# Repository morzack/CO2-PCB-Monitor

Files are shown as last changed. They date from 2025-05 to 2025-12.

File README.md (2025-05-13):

# CO2-PCB-Monitor

This repo contains the hardware and software required to manufacture and assemble a small seven segment CO2 monitor.

The monitor is built around a 4 digit seven segment display (with automatic dimming based on ambient light) that displays the current atmospheric CO2 concentration as measured by an Adafruit SCD-40 module over i2c.



In practice, this project can serve as a generic platform for any i2c module that might benefit from a 4 digit display. Potentially, other projects could be built around this architecture.

There is a BOM included: the total cost per unit, as of when it was made in early 2025, was ~90 USD.
Most of the cost comes from the SCD-40 module used -- directly integrating one of the modules onto the board should lower that price.

A rough block diagram is below:



The system has two power domains: a 5V domain is used for all digital logic, while the 3V domain is reserved for the seven-segement characters and associated dimming circuit.
This separation of power supplies was chosen to both allow for a soft startup sequence (putting less strain on the overall power supply), and to remove some voltage headroom for the LEDs.

The final design was manufactured using JLCPCB's services. A BOM is included with this repo, as well as manufacturing files.

The board can be programmed using the Arduino IDE and a separate ISP over the SPI lines.

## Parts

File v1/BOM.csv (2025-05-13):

Reference | Value | Datasheet | Footprint | Qty | DNP | stock_idx | Digikey | price per
J2 | Conn_02x03_Odd_Even | ~ | Connector_PinHeader_2.54mm:PinHeader_2x03_P2.54mm_Vertical | 1 |  | 1
JP1 | 3v3_or | ~ | Jumper:SolderJumper-2_P1.3mm_Open_Pad1.0x1.5mm | 1 |  | 1
C9 | 10u | ~ | Capacitor_SMD:C_0805_2012Metric_Pad1.18x1.45mm_HandSolder | 1 |  | 1 | https://www.digikey.com/en/products/detail/samsung-electro-mechanics/CL21A106KOQNNNE/3886754 | 0.08 | 0.08
C3,C10 | 0.1u | ~ | Capacitor_SMD:C_0805_2012Metric_Pad1.18x1.45mm_HandSolder | 2 |  | 2 | https://www.digikey.com/en/products/detail/yageo/CC0805KRX7R9BB104/302874 | 0.08 | 0.16
C4,C5,C6,C7,C8 | 100n | ~ | Capacitor_SMD:C_0805_2012Metric_Pad1.18x1.45mm_HandSolder | 5 |  | 11 | https://www.digikey.com/en/products/detail/samsung-electro-mechanics/CL21B104KBCNFNC/3888102 | 0.1 | 0.5
U1 | ATmega328P-A | http://ww1.microchip.com/downloads/en/DeviceDoc/ATmega328_P%20AVR%20MCU%20with%20picoPower%20Technology%20Data%20Sheet%2040001984A.pdf | Package_QFP:TQFP-32_7x7mm_P0.8mm | 1 |  | 25 | https://www.digikey.com/en/products/detail/microchip-technology/ATMEGA328P-AUR/2357086 | 2.74 | 2.74
Y1 | 16MHz | ~ | inv_footprints:XTAL_ECS-160-18-23A-EN-TR | 1 |  | 28 | https://www.digikey.com/en/products/detail/ecs-inc/ECS-160-18-23A-EN-TR/2213741 | 0.86 | 0.86
U2 | ~ |  | inv_footprints:scd_40 | 1 |  | 34 | https://www.digikey.com/en/products/detail/adafruit-industries-llc/5187/15194668 | 44.95 | 44.95
Q3 | 2N3904 | https://www.onsemi.com/pub/Collateral/2N3903-D.PDF | Package_TO_SOT_THT:TO-92_Inline | 1 |  | 36 | https://www.digikey.com/en/products/detail/onsemi/2N3904BU/1413 | 0.28 | 0.28
R7 | R_Photo | ~ | OptoDevice:R_LDR_5.1x4.3mm_P3.4mm_Vertical | 1 |  | 38 | https://www.digikey.com/en/products/detail/advanced-photonix/PDV-P9008/480625 | 1.49 | 1.49
U3 | MAX7221xNG | https://datasheets.maximintegrated.com/en/ds/MAX7219-MAX7221.pdf | Package_DIP:DIP-24_W7.62mm_Socket | 1 |  | 39 | https://www.digikey.com/en/products/detail/analog-devices-inc-maxim-integrated/MAX7219ENG/774127 | 18.67 | 18.67
Q1,Q2 | 2N3906 | https://www.onsemi.com/pub/Collateral/2N3906-D.PDF | Package_TO_SOT_THT:TO-92_Inline | 2 |  | 40 | https://www.digikey.com/en/products/detail/onsemi/2N3906BU/1414 | 0.27 | 0.54
SW1 | SW_Push | ~ | inv_footprints:SKQGADE010 | 1 |  | 44 | https://www.digikey.com/en/products/detail/c-k/RS-187R05A2-DS-MT-RT/2747186 | 0.72 | 0.72
LED1,LED2,LED3,LED4 | LDS-C814RI | LDS-C814RI | inv_footprints:LDS-C814RI_LUM | 4 |  | 50 | https://www.digikey.com/en/products/detail/lumex-opto-components-inc/LDS-C814RI/252593 | 2.25 | 9
R1,R6 | 10k | ~ | Resistor_SMD:R_0805_2012Metric_Pad1.20x1.40mm_HandSolder | 2 |  | 51 | https://www.digikey.com/en/products/detail/yageo/RC0805FR-0710KL/727535 | 0.14 | 0.28
R4,R8,R10,R11,R12 | 100k | ~ | Resistor_SMD:R_0805_2012Metric_Pad1.20x1.40mm_HandSolder | 5 |  | 54 | https://www.digikey.com/en/products/detail/yageo/RC0805FR-07100KL/727544 | 0.1 | 0.5
R5 | 1k | ~ | Resistor_SMD:R_0805_2012Metric_Pad1.20x1.40mm_HandSolder | 1 |  | 56 | https://www.digikey.com/en/products/detail/yageo/RC0805FR-071KL/727444 | 0.1 | 0.1
R2,R3 | 5.1k | ~ | Resistor_SMD:R_0805_2012Metric_Pad1.20x1.40mm_HandSolder | 2 |  | 60 | https://www.digikey.com/en/products/detail/panasonic-electronic-components/ERJ-6GEYJ512V/46122 | 0.1 | 0.2
C1,C2 | 18p | ~ | Capacitor_SMD:C_0805_2012Metric_Pad1.18x1.45mm_HandSolder | 2 |  | 64 | https://www.digikey.com/en/products/detail/kemet/C0805C180M3HACTU/7949065 | 0.1 | 0.2
R9 | 22k | ~ | Resistor_SMD:R_0805_2012Metric_Pad1.20x1.40mm_HandSolder | 1 |  | 65 | https://www.digikey.com/en/products/detail/stackpole-electronics-inc/RMCF0805FT22K1/1760211 | 0.1 | 0.1
U4 | MIC5205-5.0YM5 | http://ww1.microchip.com/downloads/en/DeviceDoc/20005785A.pdf | Package_TO_SOT_SMD:SOT-23-5 | 1 |  | 66 | https://www.digikey.com/en/products/detail/microchip-technology/MIC5205-5-0YM5-TR/771730 | 0.54 | 0.54
U5 | MIC5366-3.3YC5 | http://ww1.microchip.com/downloads/en/DeviceDoc/mic5365.pdf | Package_TO_SOT_SMD:SOT-353_SC-70-5 | 1 |  | 67 | https://www.digikey.com/en/products/detail/microchip-technology/MIC5366-3-3YC5-TR/1868116 | 0.12 | 0.12
C11,C12,C13,C14,C15 | 1u | ~ | Capacitor_SMD:C_0805_2012Metric_Pad1.18x1.45mm_HandSolder | 5 |  | -- mixed values -- | -- mixed values -- | #N/A | #N/A
J1,J3 | Conn_01x02 | ~ | -- mixed values -- | 2 |  | -- mixed values -- | -- mixed values -- | #N/A | #N/A
TOTAL |  |  |  |  |  |  |  |  | 82.03

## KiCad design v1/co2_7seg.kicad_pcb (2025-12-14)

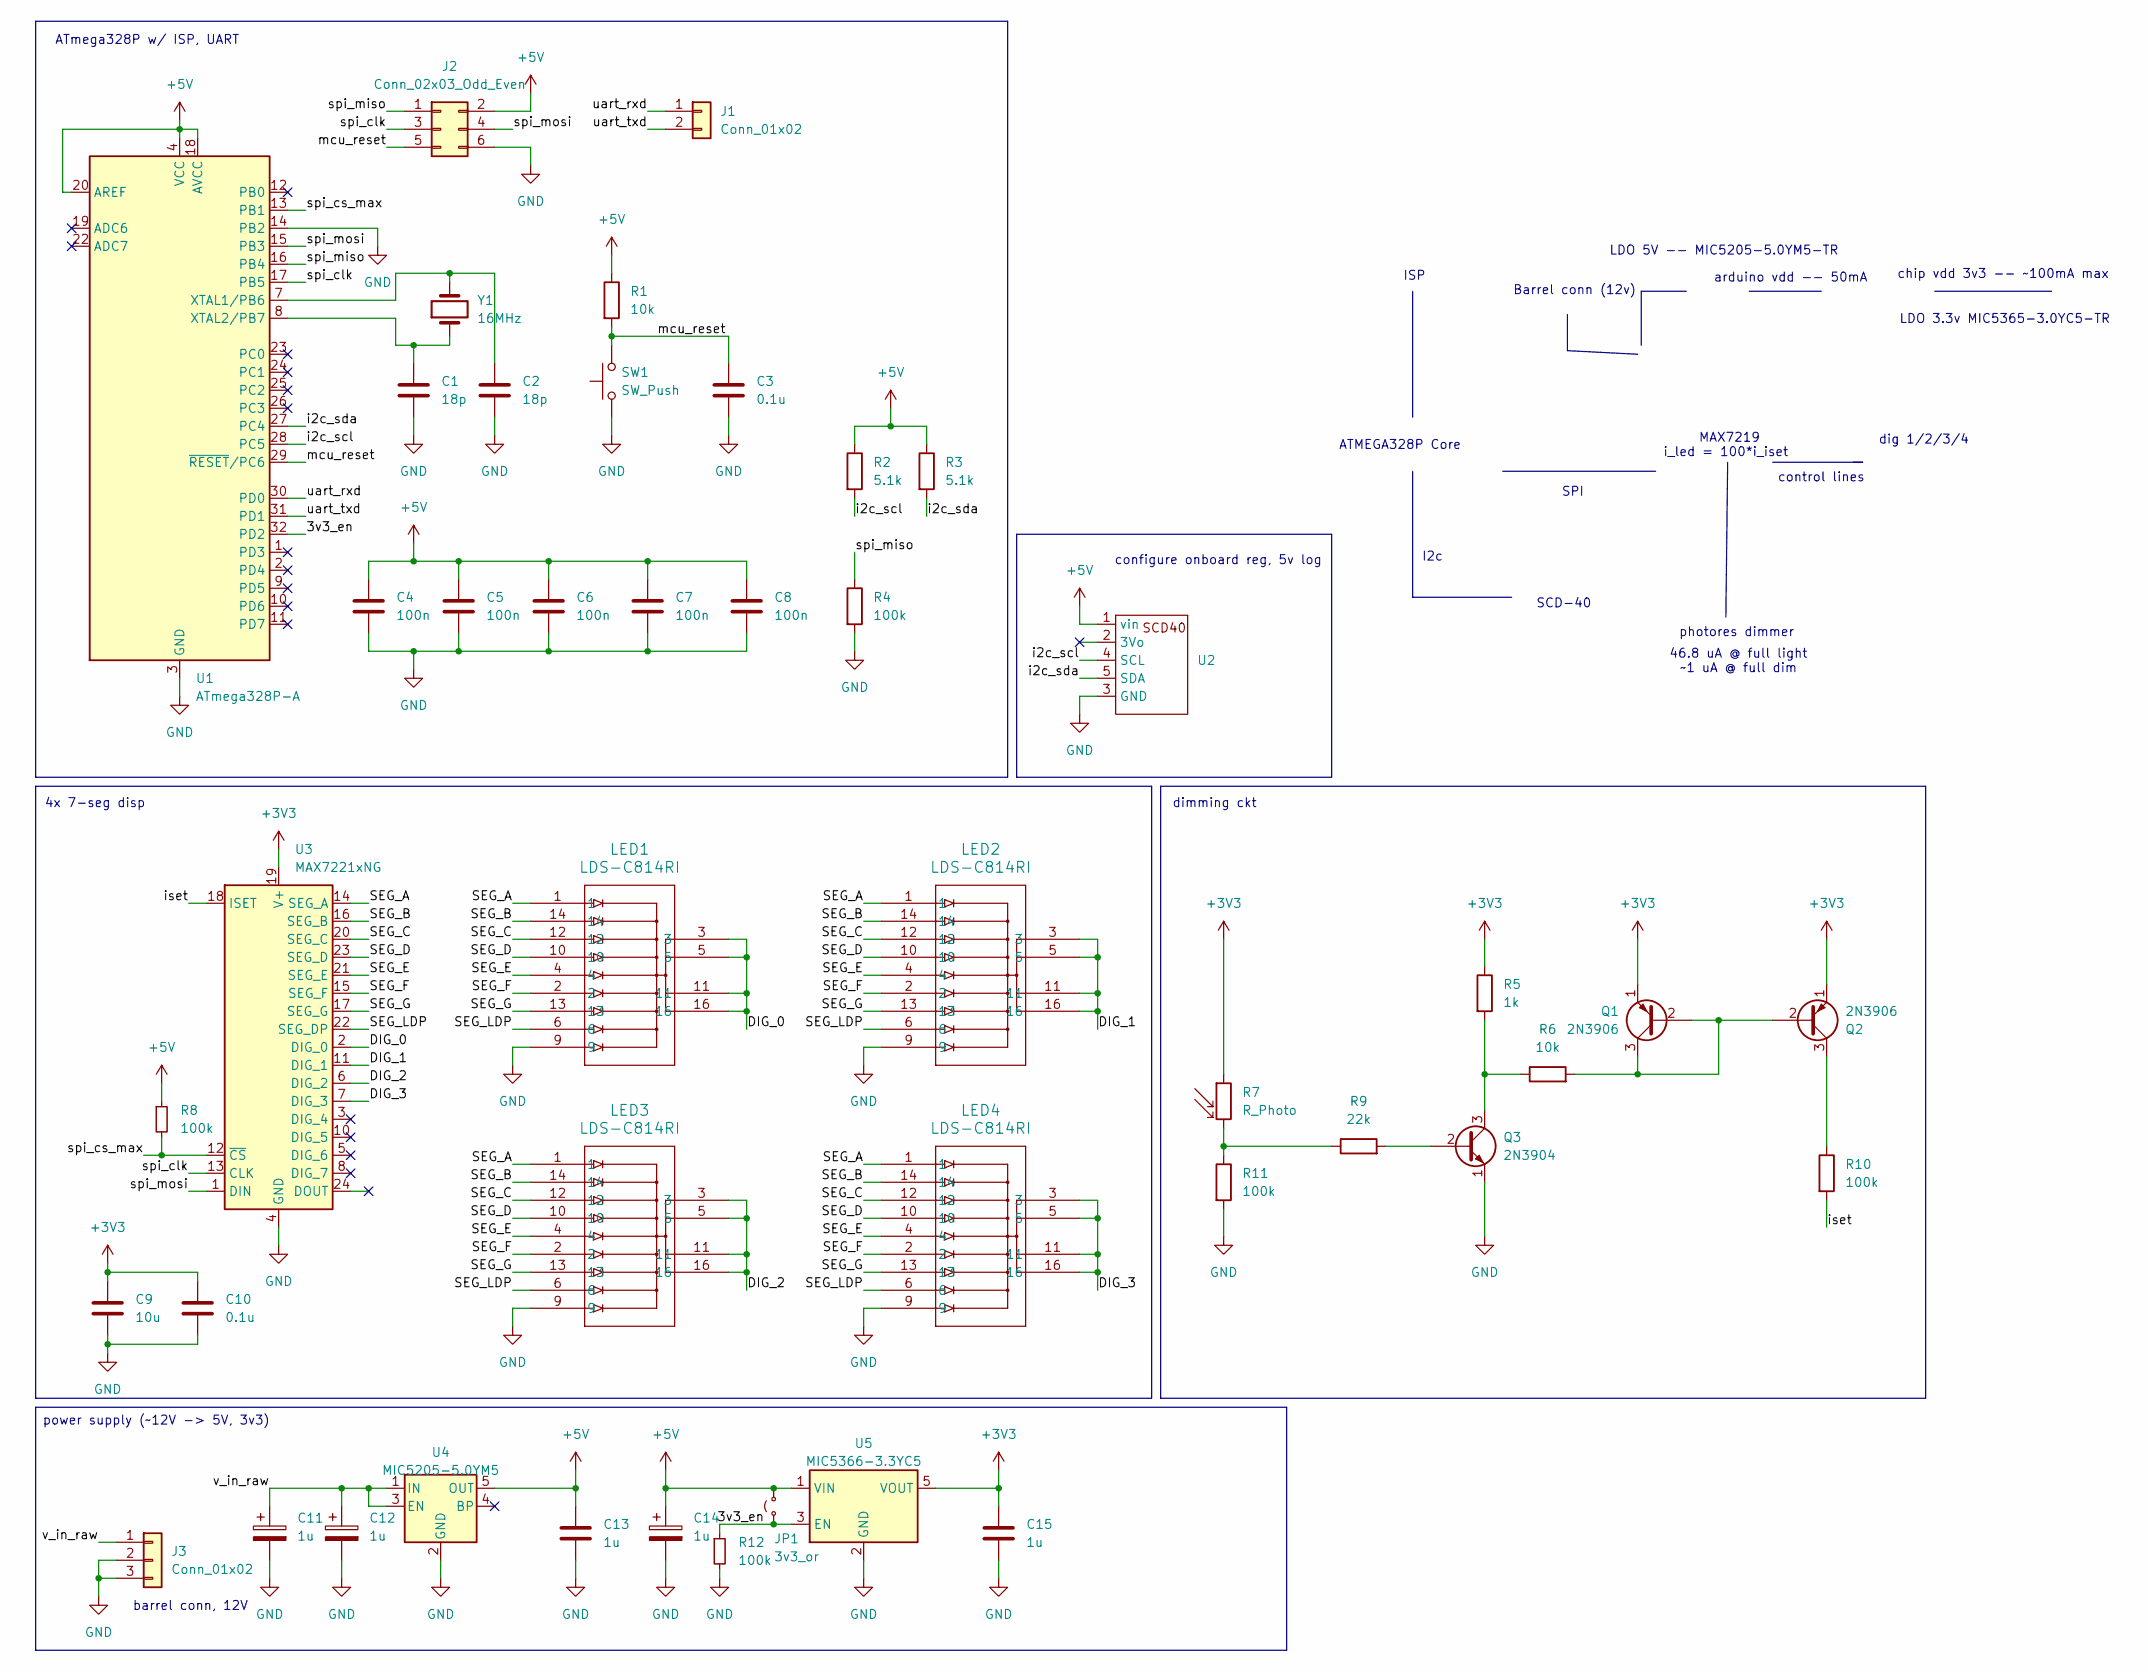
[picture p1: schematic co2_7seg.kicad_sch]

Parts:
C1, C2: 18p; C_0805_2012Metric_Pad1.18x1.45mm_HandSolder
C3, C10: 0.1u; C_0805_2012Metric_Pad1.18x1.45mm_HandSolder
C4, C5, C6, C7, C8: 100n; C_0805_2012Metric_Pad1.18x1.45mm_HandSolder
C9: 10u; C_0805_2012Metric_Pad1.18x1.45mm_HandSolder
C11, C12, C13, C14, C15: 1u; C_0805_2012Metric_Pad1.18x1.45mm_HandSolder
J1: Conn_01x02; PinHeader_1x02_P2.54mm_Vertical
J2: Conn_02x03_Odd_Even; PinHeader_2x03_P2.54mm_Vertical
J3: Conn_01x02; MPD_EJ508A
JP1: 3v3_or; SolderJumper-2_P1.3mm_Open_Pad1.0x1.5mm
LED1, LED2, LED3, LED4: LDS-C814RI; LDS-C814RI_LUM
Q1, Q2: 2N3906; TO-92_Inline
Q3: 2N3904; TO-92_Inline
R1, R6: 10k; R_0805_2012Metric_Pad1.20x1.40mm_HandSolder
R2, R3: 5.1k; R_0805_2012Metric_Pad1.20x1.40mm_HandSolder
R4, R8, R10, R11, R12: 100k; R_0805_2012Metric_Pad1.20x1.40mm_HandSolder
R5: 1k; R_0805_2012Metric_Pad1.20x1.40mm_HandSolder
R7: R_Photo; R_LDR_5.1x4.3mm_P3.4mm_Vertical
R9: 22k; R_0805_2012Metric_Pad1.20x1.40mm_HandSolder
SW1: SW_Push; SKQGADE010
U1: ATmega328P-A; TQFP-32_7x7mm_P0.8mm
U2: scd_40
U3: MAX7221xNG; DIP-24_W7.62mm_Socket
U4: MIC5205-5.0YM5; SOT-23-5
U5: MIC5366-3.3YC5; SOT-353_SC-70-5
Y1: 16MHz; XTAL_ECS-160-18-23A-EN-TR

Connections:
+3V3: C9.1, C10.1, C15.1, Q1.1 (E), Q2.1 (E), R5.1, R7.1, U3.19 (V+), U5.5 (VOUT)
+5V: C4.1, C5.1, C6.1, C7.1, C8.1, C13.1, C14.1, J2.2, JP1.2 (B), R1.1, R2.1, R3.1, R8.1, U1.4 (VCC), U1.6 (VCC), U1.18 (AVCC), U1.20 (AREF), U2.1 (vin), U4.5 (OUT), U5.1 (VIN)
/3v3_en: JP1.1 (A), R12.1, U1.32 (PD2), U5.3 (EN)
/DIG_0: LED1.3, LED1.5, LED1.11, LED1.16, U3.2 (DIG_0)
/DIG_1: LED2.3, LED2.5, LED2.11, LED2.16, U3.11 (DIG_1)
/DIG_2: LED3.3, LED3.5, LED3.11, LED3.16, U3.6 (DIG_2)
/DIG_3: LED4.3, LED4.5, LED4.11, LED4.16, U3.7 (DIG_3)
/SEG_A: LED1.1, LED2.1, LED3.1, LED4.1, U3.14 (SEG_A)
/SEG_B: LED1.14, LED2.14, LED3.14, LED4.14, U3.16 (SEG_B)
/SEG_C: LED1.12, LED2.12, LED3.12, LED4.12, U3.20 (SEG_C)
/SEG_D: LED1.10, LED2.10, LED3.10, LED4.10, U3.23 (SEG_D)
/SEG_E: LED1.4, LED2.4, LED3.4, LED4.4, U3.21 (SEG_E)
/SEG_F: LED1.2, LED2.2, LED3.2, LED4.2, U3.15 (SEG_F)
/SEG_G: LED1.13, LED2.13, LED3.13, LED4.13, U3.17 (SEG_G)
/SEG_LDP: LED1.6, LED2.6, LED3.6, LED4.6, U3.22 (SEG_DP)
/i2c_scl: R2.2, U1.28 (PC5), U2.4 (SCL)
/i2c_sda: R3.2, U1.27 (PC4), U2.5 (SDA)
/iset: R10.2, U3.18 (ISET)
/mcu_reset: C3.1, J2.5, R1.2, SW1.2, U1.29 (~RESET/PC6)
/spi_clk: J2.3, U1.17 (PB5), U3.13 (CLK)
/spi_cs_max: R8.2, U1.13 (PB1), U3.12 (~CS)
/spi_miso: J2.1, R4.1, U1.16 (PB4)
/spi_mosi: J2.4, U1.15 (PB3), U3.1 (DIN)
/uart_rxd: J1.1, U1.30 (PD0)
/uart_txd: J1.2, U1.31 (PD1)
/v_in_raw: C11.1, C12.1, J3.1, U4.1 (IN), U4.3 (EN)
GND: C1.2, C2.2, C3.2, C4.2, C5.2, C6.2, C7.2, C8.2, C9.2, C10.2, C11.2, C12.2, C13.2, C14.2, C15.2, J2.6, J3.2, J3.3, LED1.9, LED2.9, LED3.9, LED4.9, Q3.1 (E), R4.2, R11.2, R12.2, SW1.1, U1.3 (GND), U1.5 (GND), U1.14 (PB2), U1.21 (GND), U2.3 (GND), U3.4 (GND), U3.9 (GND), U4.2 (GND), U5.2 (GND)
unnamed: Q1.2 (B), Q1.3 (C), Q2.2 (B), R6.2
unnamed: Q2.3 (C), R10.1
unnamed: Q3.2 (B), R9.2
unnamed: Q3.3 (C), R5.2, R6.1
unnamed: R7.2, R9.1, R11.1
unnamed: C2.1, U1.7 (XTAL1/PB6), Y1.2
unnamed: C1.1, U1.8 (XTAL2/PB7), Y1.1

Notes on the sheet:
power supply (~12V -> 5V, 3v3)
i_led = 100*i_iset
I2c
control lines
4x 7-seg disp
dig 1/2/3/4
dimming ckt
barrel conn, 12V
LDO 3.3v MIC5365-3.0YC5-TR
46.8 uA @ full light ~1 uA @ full dim
ATMEGA328P Core
photores dimmer
Barrel conn (12v)
LDO 5V -- MIC5205-5.0YM5-TR
configure onboard reg, 5v log
SCD-40
chip vdd 3v3 -- ~100mA max
ATmega328P w/ ISP, UART
MAX7219
ISP
SPI
arduino vdd -- 50mA

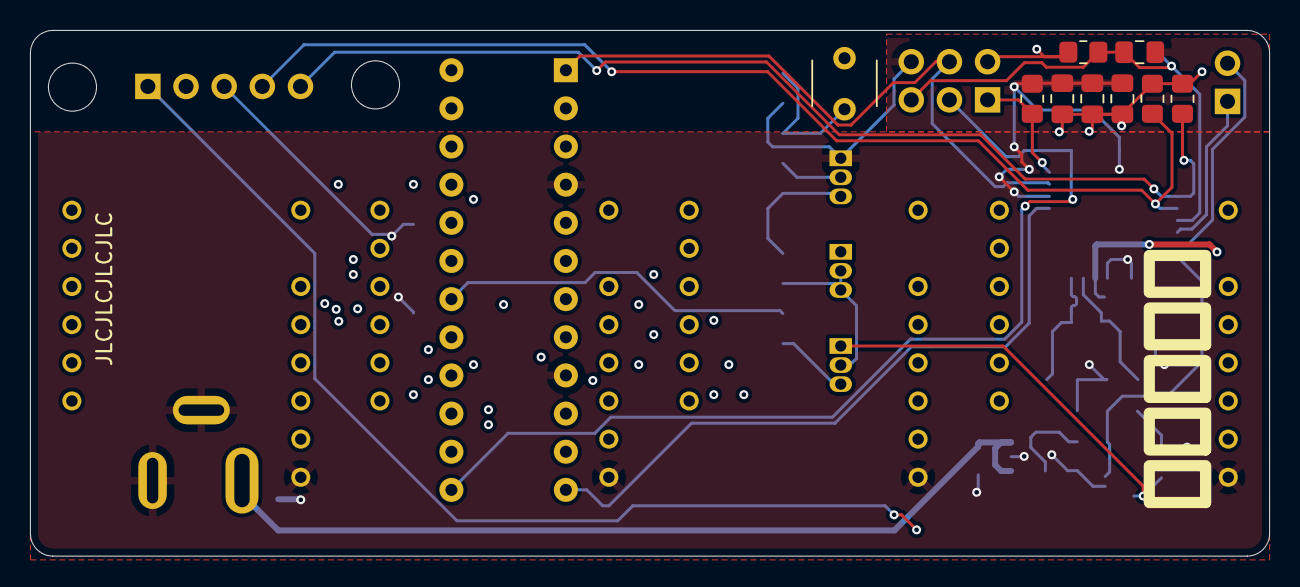
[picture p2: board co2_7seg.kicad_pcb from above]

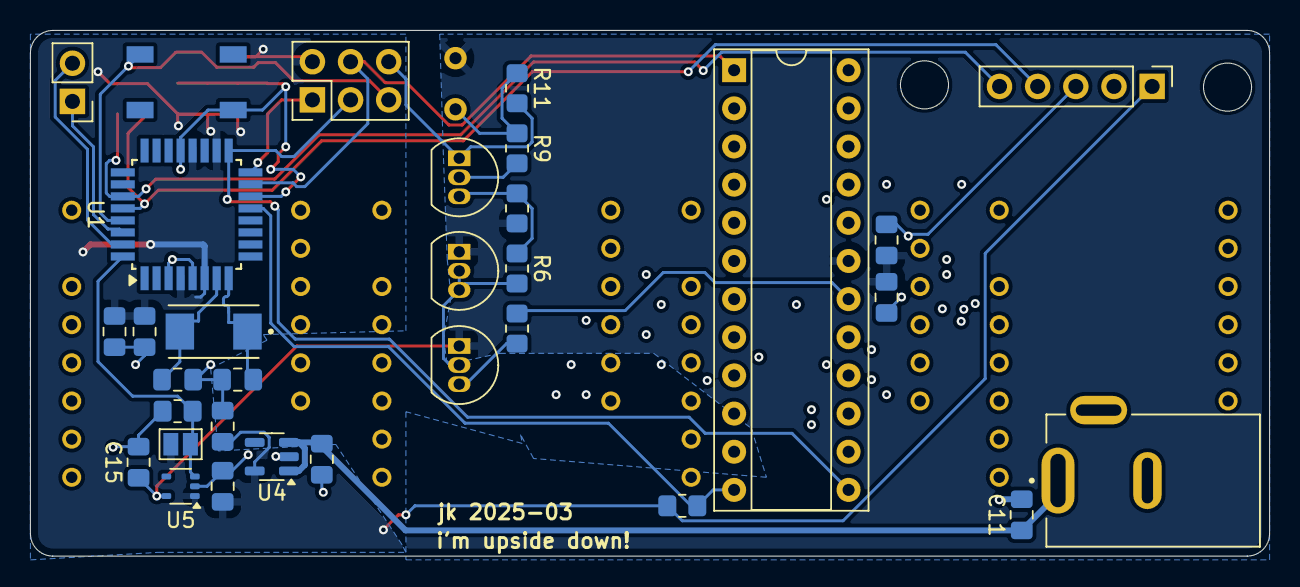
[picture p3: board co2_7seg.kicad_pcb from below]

Board: 4 copper layers, 82.5 x 35.0 mm, 45 parts (32 on the bottom side), 34 nets.

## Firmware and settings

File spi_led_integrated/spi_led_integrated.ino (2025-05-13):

#include <Arduino.h>
#include <SensirionI2CScd4x.h>
#include <Wire.h>

SensirionI2CScd4x scd4x;


// 11: MOSI/DIN
// 13: SCK/CLK
// 9: !CS (load)
// last 16 bits of serial data are latched on LOAD's rising edge

// to load data, take LOAD low, serially transmit the 16 bits of data, then set load high

// spi_clk -- PB5 = dig 13
// spi_mosi -- PB3 = dig 11
// spi_cs_max -- PB1 = dig 9
#define PIN_DIN 11
#define PIN_CLK 13
#define PIN_LOAD 9

#define PIN_EN_3V 2 // PD2 = dig 2

// #define PIN_DIN 11
// #define PIN_CLK 13
// #define PIN_LOAD 8

// #define PIN_CLK 6
// #define PIN_LOAD 5
// #define PIN_DIN 13

void send_bit(uint8_t bit);
void send_data_raw(uint16_t dat);
void write_reg(uint8_t reg, uint8_t dat);

#define CHAR_0 0x0
#define CHAR_1 0x1
#define CHAR_2 0x2
#define CHAR_3 0x3
#define CHAR_4 0x4
#define CHAR_5 0x5
#define CHAR_6 0x6
#define CHAR_7 0x7
#define CHAR_8 0x8
#define CHAR_9 0x9
#define CHAR_DASH 0xA
#define CHAR_E 0xB
#define CHAR_H 0xC
#define CHAR_L 0xD
#define CHAR_P 0xE
#define CHAR_BLANK 0xF

void write_digit(uint8_t digit, uint8_t character);

void make_co2_reading();
uint16_t last_co2;
float last_humid;
float last_temp;

void setup() {
  Wire.begin();
  uint16_t error;

  pinMode(PIN_DIN, OUTPUT);
  pinMode(PIN_CLK, OUTPUT);
  pinMode(PIN_LOAD, OUTPUT);
  pinMode(PIN_EN_3V, OUTPUT);

  digitalWrite(PIN_DIN, LOW);
  digitalWrite(PIN_CLK, LOW);
  digitalWrite(PIN_LOAD, HIGH);
  digitalWrite(PIN_EN_3V, LOW);

  // soft bringup the max chip
  delay(1000);
  digitalWrite(PIN_EN_3V, HIGH);
  delay(2000);

  // turn on only digit 0
  write_reg(0x9, 0xFF); // decode mode: 
  write_reg(0xA, 0x0F); // intensity
  write_reg(0xB, 0x03); // 0x3 for 4 digits
  write_reg(0xC, 0x01); // shutdown

  delay(1000);

  // bring up co2 sense
  scd4x.begin(Wire);
  error = scd4x.stopPeriodicMeasurement();
  error = scd4x.startLowPowerPeriodicMeasurement();

  write_num(0);
}

void loop() {
  // cycle through test digits
  // uint8_t x = 0;
  // while (x <= 9) {    
  //   write_digit(0, x);

  //   if (x == 9) {
  //     x = 0;
  //   }
  //   x++;

  //   delay(1000);
  // }

  // uint16_t a = 0;
  // uint16_t inc = 59;
  // while (a <= 9999) {
  //   write_num(a);
  //   if (a > 9999) {
  //     a %= 9999;
  //   }
  //   else {
  //     a += inc;
  //   }
  //   delay(250);
  // }

  make_co2_reading();
  write_num(last_co2);

  unsigned long startMillis = millis();
  while (millis() - startMillis < (1000UL * 60UL * 5UL)); // wait 5m between readings
}


void make_co2_reading() {
  bool is_data_ready = false;
  uint16_t err = scd4x.getDataReadyFlag(is_data_ready);
  if (err) {
    return;
  }

  if (!is_data_ready) {
    return;
  }

  uint16_t tmp_co2;
  err = scd4x.readMeasurement(tmp_co2, last_temp, last_humid);
  if (err) {
    return;
  }

  if (tmp_co2 != 0) {
    last_co2 = tmp_co2;
  }
}

void send_bit(uint8_t bit) {
  // bring data to value
  digitalWrite(PIN_DIN, bit == 0 ? LOW : HIGH);
  // wait a bit
  delay(1); // 1
  // bring clock high to latch value
  digitalWrite(PIN_CLK, HIGH);
  delay(1); // 3
  
  // bring clock low/hold, prep for next
  digitalWrite(PIN_CLK, LOW);
  delay(1); // 4
}

void send_data_raw(uint16_t dat) {
  digitalWrite(PIN_CLK, LOW);
  digitalWrite(PIN_LOAD, LOW);
  digitalWrite(PIN_DIN, LOW);
  delay(1); // 50
  for (uint8_t i=0; i<16; i++) {
    uint8_t b = (dat>>(15-i)) & 0x01;
    send_bit(b);
  }
  digitalWrite(PIN_LOAD, HIGH);
  digitalWrite(PIN_CLK, LOW);
  digitalWrite(PIN_DIN, LOW);
}

void write_reg(uint8_t reg, uint8_t dat) {
  uint16_t sending = 0x00;
  sending |= dat;
  sending |= (reg << 8);
  send_data_raw(sending);
}

void write_digit(uint8_t digit, uint8_t character) {
  // assume digit is zero-indexed
  write_reg(digit+1, character);
}

void write_num(uint16_t num) {
  uint8_t a = num % 10;
  uint8_t b = (num/10) % 10;
  uint8_t c = (num/100) % 10;
  uint8_t d = (num/1000) % 10;
  write_digit(3, a);
  write_digit(2, b);
  write_digit(1, c);
  write_digit(0, d);
}

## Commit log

2025-05-13 Add KiCad + src project files
    TODO make new repo for shared symbols, update path + add as submodule
    [co2_7seg-CuBottom.gbr, co2_7seg-CuIn1.gbr, co2_7seg-CuIn2.gbr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]
2025-05-13 add reference to footprint libs, add BOM
    [BOM-co2_7seg.csv, BOM.csv, co2_7seg.kicad_sch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]
2025-05-13 update kicad schematic to include digikey link(s)
2025-12-14 move project structure
    [BOM-co2_7seg.csv, BOM.csv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]
